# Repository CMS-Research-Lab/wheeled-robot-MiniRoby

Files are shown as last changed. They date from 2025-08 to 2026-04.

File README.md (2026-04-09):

# Prototipo Educativo de Robot Móvil MiniRoby

<p align="center">
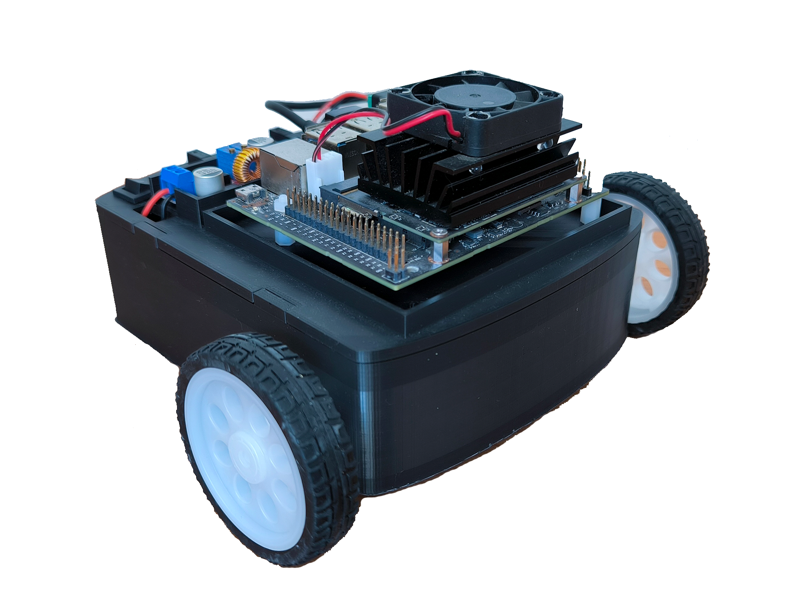
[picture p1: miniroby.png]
Robot MiniRoby
  
</p>

<p align="center">
  <b>Robot móvil diferencial de bajo costo para educación e investigación</b>
</p>

<p align="center">
  
  
  
  
</p>

---

## Publicación asociada

Este repositorio contiene los archivos del artículo:

**"Construction of an Educational Prototype of a Differential Wheeled Mobile Robot"**  
Autores: Celso Márquez-Sánchez, Jacobo Sandoval-Gutiérrez y Daniel Librado Martinez-Velazquez  
Revista: *Hardware* (MDPI)

Como citar:

Márquez-Sánchez, C., Sandoval-Gutiérrez, J., & Martínez-Vázquez, D. L. (2026). Construction of an Educational Prototype of a Differential Wheeled Mobile Robot. Hardware, 4(1), 2. https://doi.org/10.3390/hardware4010002

---

## Descripción del proyecto

MiniRoby es un robot móvil diferencial, de bajo costo e impreso en 3D, diseñado para:

- Enseñanza de robótica móvil  
-  Investigación en control y seguimiento de trayectorias  
-  Desarrollo de sistemas embebidos modulares  

El sistema integra:
-  **Arduino Nano** → Control de bajo nivel (motores, PWM, encoders)  
-  **Jetson Nano** → Procesamiento, control y generación de trayectorias  
-  **Estructura impresa en 3D** → Diseño modular y replicable  

---

## 📦 Contenido del repositorio

- 📁 `/stl` → Archivos STL para impresión 3D  
- 📁 `/arduino` → Código para control de motores  
- 📁 `/jetson` → Scripts en Python para control y trayectorias  
- 📁 `/videos` → Ejecución de trayectorias (lineal, circular, sinusoidal)  

---

## Estado del proyecto

⚠️ Este prototipo se encuentra en desarrollo.

El diseño, código y estrategias de control están en **constante evolución**.  
Se recomienda revisar este repositorio periódicamente para acceder a:

-  Mejoras  
-  Correcciones  
-  Nuevas funcionalidades experimentales  

---

##  Aplicaciones

- Seguimiento de trayectoria  
- Control de robots diferenciales  
- Sistemas embebidos educativos  
- Experimentación en robótica móvil  

---

##  Contribuciones

Las contribuciones son bienvenidas.  
Puedes aportar mediante:

- Mejoras en código  
- Optimización de diseño  
- Nuevas estrategias de control  
- Documentación  

---

## Como Citar el trabajo

> Por favor, cite la publicación original al utilizar o adaptar cualquier parte de este proyecto.

MDPI and ACS Style

Márquez-Sánchez, C.; Sandoval-Gutiérrez, J.; Martínez-Vázquez, D.L. Construction of an Educational Prototype of a Differential Wheeled Mobile Robot. Hardware 2026, 4, 2. https://doi.org/10.3390/hardware4010002

AMA Style

Márquez-Sánchez C, Sandoval-Gutiérrez J, Martínez-Vázquez DL. Construction of an Educational Prototype of a Differential Wheeled Mobile Robot. Hardware. 2026; 4(1):2. https://doi.org/10.3390/hardware4010002

Chicago/Turabian Style

Márquez-Sánchez, Celso, Jacobo Sandoval-Gutiérrez, and Daniel Librado Martínez-Vázquez. 2026. "Construction of an Educational Prototype of a Differential Wheeled Mobile Robot" Hardware 4, no. 1: 2. https://doi.org/10.3390/hardware4010002

APA Style

Márquez-Sánchez, C., Sandoval-Gutiérrez, J., & Martínez-Vázquez, D. L. (2026). Construction of an Educational Prototype of a Differential Wheeled Mobile Robot. Hardware, 4(1), 2. https://doi.org/10.3390/hardware4010002

---

## 📬 Contacto

**Celso Márquez-Sánchez**  
Universidad Autónoma Metropolitana – Lerma, México  
📧 c.marquez@correo.ler.uam.mx  

---

<p align="center">
  Si este proyecto te es útil, considera darle una estrella en GitHub ⭐
</p>

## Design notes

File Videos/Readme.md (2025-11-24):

# Demonstration Videos – Educational Mobile Robot Prototype
This folder contains three video files demonstrating the physical execution of different reference trajectories by the educational mobile robot prototype described in the article:
**"Construction of an Educational Prototype of a Differential Wheeled Mobile Robot"**  
Authors: Celso Márquez-Sánchez, et la.
Journal: *Hardware* (MDPI)

## Description of Videos
Each video corresponds to a specific trajectory generated by the Jetson and followed by the robot using its onboard control system:
- `linear_trajectory.mp4`:  
  The robot moves in a straight path at constant velocity. This demonstrates the basic tracking performance of the system for a linear reference.
- `circular_trajectory.mp4`:  
  The robot follows a circular path, validating the control system's ability to track a continuously curving trajectory.
- `sinusoidal_trajectory.mp4`:  
  The robot executes a sinusoidal path, showing the system’s performance under varying curvature and more complex movement patterns.

> All videos were recorded in real-time conditions with the system described in the article, including the Jetson-based controller and 3D-printed chassis.

Due to file size limitations, the trajectory tracking videos are hosted externally on YouTube.
Each video shows the robot executing a specific reference trajectory in real time:

- 🔗 [Linear trajectory](https://youtube.com/shorts/kx4eUDEefHU)
- 🔗 [Circular trajectory](https://youtube.com/shorts/RYR4Zf6cxJA)
- 🔗 [Sinusoidal trajectory](https://youtube.com/shorts/dJWP5NK1ZKQ)
- 🔗 [Complex trajectory](https://youtu.be/_qh-XZkj5wg)

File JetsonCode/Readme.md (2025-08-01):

# Jetson Scripts – Educational Mobile Robot Prototype
This directory contains the Python scripts developed for execution on the Jetson Nano, as part of the educational mobile robot prototype described in the article:
**"Construction of an Educational Prototype of a Differential Wheeled Mobile Robot"**  
Authors: Celso Márquez-Sánchez, et la.
Journal: *Hardware* (MDPI)

## Description
The scripts in this folder implement the core functionalities for real-time trajectory tracking, velocity control, and serial communication between the Jetson and the Arduino Nano.
## Script Descriptions
- `principalHardware.py`:  
  Main script that runs the control loop. It handles the execution of the trajectory, communication with the Arduino Nano, and plotting of the tracking results.
- `trajectory.py`:  
  Generates reference trajectories such as linear, circular, or sinusoidal for the robot to follow.
- `PD.py`:  
  Contains the implementation of the controller used to calculate the desired velocities based on the tracking error.

- `atan3.py`:  
  Auxiliary script that defines an extended `atan2` function with angle wrapping to ensure consistent orientation error computation.

- `test/`:  
  Directory for optional test scripts or experimental modules used during development or debugging.

## Requirements
- Jetson Nano or Jetson Orin running Ubuntu 18.04/20.04
- Python 3.6 or newer
- Required Python packages:
  - `numpy`
  - `pyserial`
  - `matplotlib`

## How to Run
1. Ensure the Arduino Nano is connected via USB and running its corresponding motor control code.
2. From the Jetson terminal, navigate to the folder containing the scripts.
3. Run the main script:
   ```bash
   sudo python3 principalHardware.py

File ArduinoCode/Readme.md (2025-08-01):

# Arduino Nano Code – Educational Mobile Robot Prototype
This folder contains the source code developed for the **Arduino Nano** board, used in the prototype presented in the article:
**"Construction of an Educational Prototype of a Differential Wheeled Mobile Robot"**  
Authors: Celso Márquez-Sánchez, et al.  
Journal: *Hardware* (MDPI)

## Code Functionality
The code implements basic differential drive control for the robot, enabling:
- Motor control via an H-bridge driver
- Reading speed commands via serial communication
- Speed modulation using PWM

## Requirements
- Board: Arduino Nano
- Library: `PinChangeInterrupt.h`  
  > ⚠️ Note: This library must be installed before uploading the program.

## Additional Notes
- The code is intended to be used with the 3D-printed mobile robot whose design files are provided in the `stl/` folder.
- Emergency stop logic is currently declared but not implemented.

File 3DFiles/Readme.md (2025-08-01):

# STL Files for the Educational Mobile Robot Prototype
This directory contains the STL files used for 3D printing the prototype presented in the article:
**"Construction of an Educational Prototype of a Differential Wheeled Mobile Robot"**  
Authors: Celso Márquez-Sánchez, et al.
Journal: *Hardware* (MDPI)

## 📦 Included Files
Each STL file corresponds to a specific part of the robot's chassis or structure:

- `chasis.stl`: Main body of the robot. Serves as the structural base where all other components such as motors, wheels, electronics, and supports are mounted.
- `cover.stl`: Top cover of the robot, used to protect internal components such as the battery, wiring, and controller board.
- `ballCasterBase.stl`: Support structure for a front ball caster, used to stabilize the robot and allow smooth movement along the floor.
- `shaftCoupling.stl`: Coupling piece designed to connect the motor shaft to the wheel or drive axle, ensuring secure transmission of torque.

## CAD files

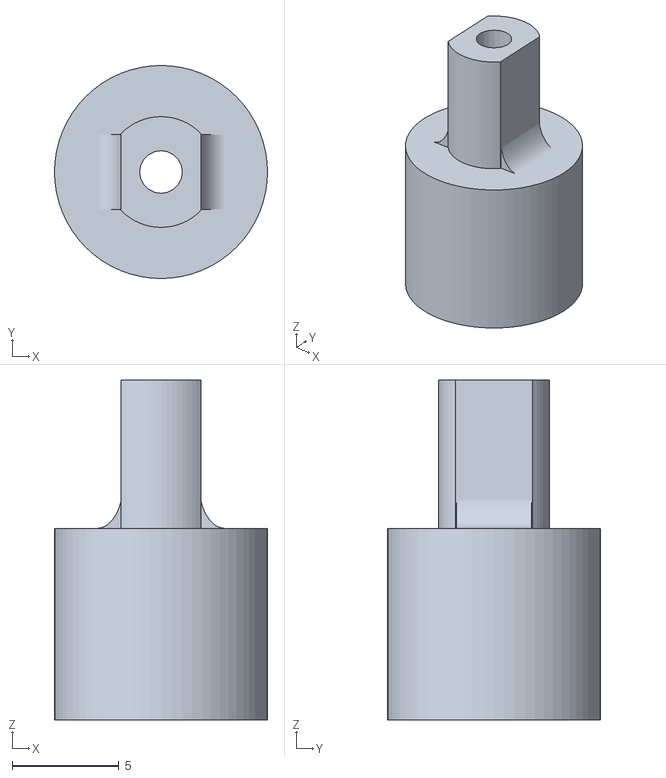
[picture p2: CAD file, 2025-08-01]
3DFiles/shaftCoupling.stl
10.0 x 10.0 x 16.0

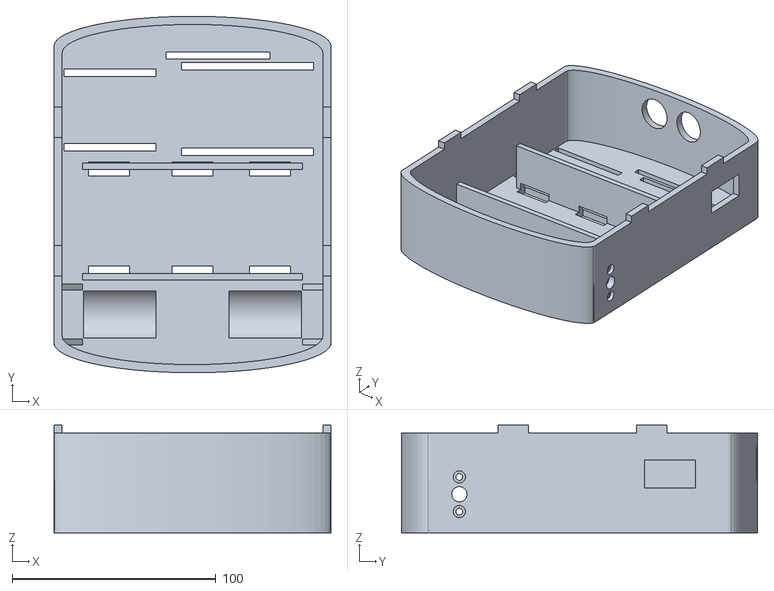
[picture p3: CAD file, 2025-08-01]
3DFiles/chasis.stl
136.0 x 175.0 x 53.0

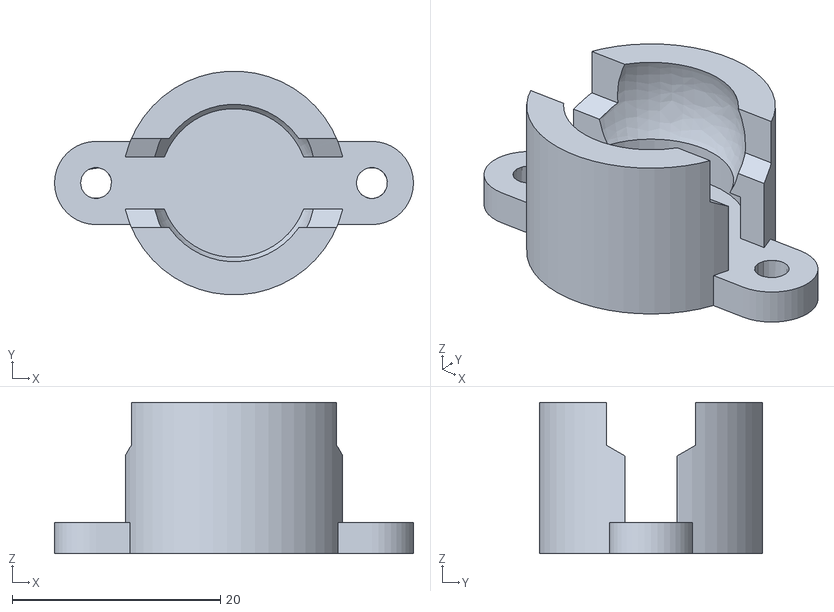
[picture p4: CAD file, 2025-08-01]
3DFiles/ballCasterBase.stl
34.5 x 21.5 x 14.6

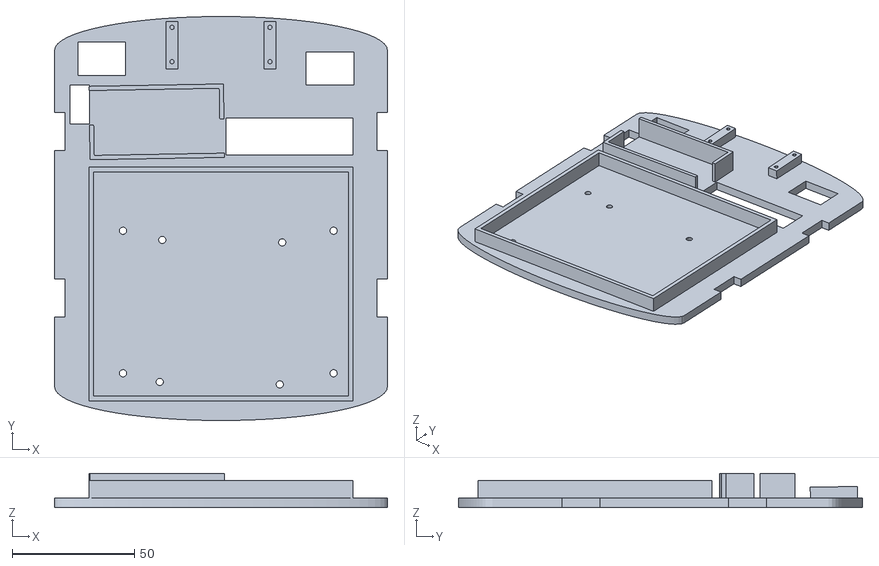
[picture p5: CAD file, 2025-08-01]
3DFiles/cover.stl
136.0 x 165.0 x 14.0

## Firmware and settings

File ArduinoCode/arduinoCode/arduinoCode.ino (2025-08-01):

/******************************************
  Date: 07-2025
  Authors: CMS, JSG, DLM
  Board: Arduino Nano
  Description: 
  This code controls a two-wheeled differential mobile robot using an Arduino Nano.
  It receives velocity commands from a Single Board Computer (Jetson Nano) via serial communication,
  drives two motors through a H-bridge, and calculates angular velocities of the wheels
  using quadrature encoders.
  
  Note: It is necessary to install the PinChangeInterrupt.h library before uploading the program to the Arduino board.

  Key functionalities:
  - Serial communication with SBC for receiving motor commands
  - Velocity decoding and PWM generation for each motor
  - Encoder signal processing with interrupts
  - Real-time calculation of angular velocities
*******************************************/
// Library to use multiple interrupt pins on Arduino Nano
#include "PinChangeInterrupt.h"

//-------------------- Variable Declarations -------------------------
// H-bridge pin definitions
#define IN1izq 6
#define IN2izq 7
#define pwm_i 11
#define pwm_d  10
#define IN1der 8
#define IN2der 9

int ledPin = 13;
char comando;  // Incoming serial character command
int valor = 0 ;
int signo=1;  // Sign of the velocity command
double PWM_der = 0.0;
double PWM_izq = 0.0;
int motor_der=0;
int motor_izq=0;
volatile bool  paroEmergencia = false; // Emergency stop flag
unsigned long lastTime, sampleTime = 100;
//------------------------------------------------------------------------------------------------

//------------------ Serial Communication Variables ---------------------
String velocidadRuedas = "";
String lastVelocidadRuedas = "";

//------------------ Right Motor Encoder ----------------------
const int    CAR = 2;    // Encoder A channel
const int    CBR = 3;    // Encoder B channel
volatile int tickR = 0;
volatile int antR      = 0;
volatile int actR      = 0;
double omegaR = 0; // Angular velocity of right wheel

//------------------ Left Motor Encoder -----------------------
const int    CAL = 4; // Encoder A channel.
const int    CBL = 5; // Encoder B channel
volatile int tickL = 0;
volatile int antL      = 0;
volatile int actL      = 0; 
double omegaL = 0; // Angular velocity of left wheel

//------------ Constants for velocity calculation ------------
double constValue = 3.1733; // (1000*2*pi)/R ---> R = 1980 (encoder resolution x4)

void setup()
{
  // Pin setup and serial configuration
  pinMode(ledPin,OUTPUT);
  digitalWrite(ledPin,LOW);
  pinMode(pwm_i, OUTPUT);
  pinMode(pwm_d, OUTPUT);
  pinMode(IN1izq, OUTPUT);
  pinMode(IN2izq, OUTPUT);
  pinMode(IN1der, OUTPUT);
  pinMode(IN2der, OUTPUT);
  Serial.begin(115200);
  
  // Encoder input pin setup
  pinMode(CAR, INPUT);
  pinMode(CBR, INPUT);
  pinMode(CAL, INPUT);
  pinMode(CBL, INPUT);
  
  // Attach interrupts for encoder signals
  attachInterrupt(digitalPinToInterrupt(CAR), encoderR, CHANGE);
  attachInterrupt(digitalPinToInterrupt(CBR), encoderR, CHANGE);
  attachPinChangeInterrupt(digitalPinToPinChangeInterrupt(CAL), encoderL, CHANGE);
  attachPinChangeInterrupt(digitalPinToPinChangeInterrupt(CBL), encoderL, CHANGE);             

  lastTime = millis(); // Initialize timer
     
}
void loop() {
  
  if(millis()-lastTime >= sampleTime)
  {
    omegaR = constValue*tickR/(millis()-lastTime);
    omegaL = constValue*tickL/(millis()-lastTime);
    lastTime = millis();
    tickR = 0;
    tickL = 0;
    // Format velocity string for transmission    
    velocidadRuedas = "r,";
    velocidadRuedas += omegaR;
    velocidadRuedas += ",l,";
    velocidadRuedas += omegaL;
    velocidadRuedas += ",";
  }
  
  // Send new velocity string only if it has changed
  if (!velocidadRuedas.equals(lastVelocidadRuedas)){
    Serial.println(velocidadRuedas);
  }
  lastVelocidadRuedas=velocidadRuedas;
  
  // Emergency stop logic, Note: This option is currently not implemented 
  if (paroEmergencia == true)
  {
    digitalWrite(ledPin,HIGH);
   analogWrite(pwm_d, 0);
   analogWrite(pwm_i, 0);
  }
  else
  {
    // Receive and process serial motor commands
    if (Serial.available() > 0)
      {      
        comando = ((byte)Serial.read());
        if(isDigit(comando))//es un valor entre 0-9
        {
          valor = (valor*10)+(comando-'0');
           
        }
        else if (comando == '-')
        {
          signo=-1;
        }
        else if (comando == 'D')
        {
          // Right motor control 
          digitalWrite(ledPin,HIGH);           
          PWM_der=valor/100.0;          
          motor_der=(int)((PWM_der)*255);
                   
          if (signo>0 ){        
            digitalWrite(IN1der,LOW);
            digitalWrite(IN2der,HIGH);        
          }
          else
          {
            digitalWrite(IN1der,HIGH);
            digitalWrite(IN2der,LOW);
          }    
          analogWrite(pwm_d, motor_der);                                   
          valor=0;
          signo=1;
          PWM_der=0.0;    
        }  
        else if (comando == 'I')
        {                      
          PWM_izq=valor/100.0;
          motor_izq=(int)((PWM_izq)*255);
          if (signo>0 )
          {
            digitalWrite(IN1izq,HIGH);
            digitalWrite(IN2izq,LOW);
          }
          else
          {
            digitalWrite(IN1izq,LOW);
            digitalWrite(IN2izq,HIGH);
          }
          analogWrite(pwm_i, motor_izq);
          valor=0;
          signo=1;
          PWM_izq=0.0;
        }          
        else if (comando == '.')      
        {
          valor=valor;
        }
        else
        {
          signo=1;
        }    
      }
    }      
}


void encoderR(void)
{
    antR=actR;             
    actR=PIND & 12;  
    
    if(antR==0  && actR== 4){
       tickR=tickR+1;
    } 
    if(antR==4  && actR==12){
       tickR=tickR+1;
    } 
    if(antR==8  && actR== 0){
      tickR=tickR+1;
    }  
    if(antR==12 && actR== 8){
      tickR=tickR+1;
    }  
    
    if(antR==0 && actR==8){
      tickR=tickR-1;
    }   
    if(antR==4 && actR==0){
      tickR=tickR-1;
    }  
    if(antR==8 && actR==12){
      tickR=tickR-1;
    } 
    if(antR==12 && actR==4){
      tickR=tickR-1;
    }       

}
void encoderL(void)
{
    antL=actL;                
    actL=PIND & 48;                 
                                       
    if(antL==0  && actL==16){
      tickL=tickL+1;
    }  
    if(antL==16 && actL==48){
      tickL=tickL+1;
    }  
    if(antL==32 && actL== 0){
      tickL=tickL+1;
    }  
    if(antL==48 && actL==32){
      tickL=tickL+1;
    }  
    
    if(antL==0  && actL==32){
      tickL=tickL-1;
    }   
    if(antL==16 && actL== 0){
      tickL=tickL-1;
    }  
    if(antL==32 && actL==48){
      tickL=tickL-1;
    }  
    if(antL==48 && actL==16){
      tickL=tickL-1;
    }  
    
}

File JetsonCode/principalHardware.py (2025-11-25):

#!/usr/bin/python
""" 
Title           : principal.py
Description     : Main program for trajectory tracking. It sends torque data via the serial port to Arduino, 
                  which is connected to a H-bridge. The program uses the kinematic model of a 
                  Rigid Mobile Robot (RMR) to estimate the robot's position. Arduino calculates the angular 
                  velocities of the wheels and sends them via USB to the program.
Author          : CMS, JSG, DLM
Date            : July 2025
Python_version  : 3.0
Dependencies    : matplotlib, numpy, scipy, serial, multiprocessing, RPi.GPIO
"""
#==============================================================================
import PD
import atan3
from time import time, sleep
import matplotlib.pyplot as plt
import trajectory
import serial
import scipy as sp
import numpy as np
from multiprocessing import Process, Value
import RPi.GPIO as GPIO

# Set up GPIO pins
GPIO.setmode(GPIO.BCM)

# GPIO for the emergency stop button
paro = 17

# Assign the emergency stop button to the GPIO pin
GPIO.setup(paro,GPIO.IN)

# Sampling time
Ts = 0.001

# Create a connection with Arduino, specify connection speed
# Find the port: dmesg | grep "tty"
try:
    arduino = serial.Serial('/dev/ttyUSB0', 115200, timeout=1)    
    sleep(1.8) 
    arduino.flushInput()
    arduino.flushOutput()
except:
    print("Check the connection with Arduino")

# Kinematic control
pd = PD.PD(5.0, 1.0, 5.0)
kpd = 0.6
kid = 0.1
kpi = 0.6
kii = 0.1

atan = atan3.atangente()

#*******************
# RMR parameters
# MiniRoby
#*******************
r = 0.0325 #Wheel radius
l = 0.09 #track width

# RMR arrays
x_list = []
y_list = []
phi_list = []
w = []
wd_list = []
wi_list = []
v_list = []

xd_list = []
yd_list = []

i = 0

# Initial conditions of the RMR
x = 0.67
y = 0.0
phi = 0.0

# Initialize variables
time_list = []
PWM_der = 0
PWM_izq = 0
wdr = 0.0
wir = 0.0
phir_list = []
vr_list = []
wr_list = []
v_list = []

# PI control variables
ed = 0.0
ei = 0.0
ud = 0.0
ui = 0.0
iei = 0.0
ied = 0.0

#**********************************************************
# Function to read the speeds calculated by Arduino
#**********************************************************
def LecturaVelocidades():
    serial=[]
    rx = 0
    cadena = ",,,"
    lastcadena = ",,,"
    texto = []
    inicio=time()

    while 1:
        if terminar1.value == 0:
            cadena = str(arduino.readline())
            if cadena != "":                
                lastcadena = cadena
                texto = cadena.split(",")
                rx += 1
                if len(texto) > 0:
                    try:
                        if texto[2] == "l":
                            angularI.value = float(texto[3])
                        if texto[0] == "b'r":
                            angularD.value = float(texto[1])
                    except:
                        print("Error reading encoder data")
        else:
            sleep(0.01)
            print ("Arduino reading subprocess terminated")
            break

#*********************************************************
# Write to Arduino                                      *
#*********************************************************
def escritura_Arduino(terminar1, PWMD1, PWMI1):
    last = 0
    valor = ""
    while 1:
        if terminar1.value == 0:
            if PWMD1.value != last or PWMI1.value != last:                
                valor=str(PWMD1.value) + 'D' +',' +str(PWMI1.value) + 'I'+','
                arduino.write(bytes(valor,encoding='windows-1255'))
        else:
            sleep(0.01)
            valor=str(0) + 'D' +',' +str(0) + 'I'+','
            arduino.write(bytes(valor,encoding='windows-1255'))
            print ("Arduino writing subprocess terminated")
            break
#************************************************************************************************************************

terminar1 = Value('i', 0)
PWMI = Value('i', 0)
PWMD = Value('i', 0)
angularI = Value('f', 0.0)
angularD = Value('f', 0.0)

# Start subprocess for writing commands to Arduino
subproceso = Process(target=escritura_Arduino, args=(terminar1, PWMD, PWMI))
subproceso.start()

# Start subprocess for reading wheel speeds from Arduino
subproceso1 = Process(target=LecturaVelocidades)
subproceso1.start()

# Initialize test parameters
duracion = 0
duracion2 = []
inicio = 0
tauD = 0
tauI = 0

#ERRORES
errorX_list = []
errorY_list = []
ephi_list = []

phir=0.0
phir_list2=[]
path = trajectory.trayectoria()

j = 10
k = 0
inicio = time()
pulsos_list = []
xp_list = []
yp_list = []
ud_list = []
ui_list = []

q = 0
antduracion = 0.0
print ("Start of the experiment")

#tiempo de muestreo en segundos
milis = 0.001
mm = 1
t_experimento = 15.0	
inicio = time()
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

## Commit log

2025-08-01 Create jetson
2025-08-01 Update and rename jetson to Readme.md
